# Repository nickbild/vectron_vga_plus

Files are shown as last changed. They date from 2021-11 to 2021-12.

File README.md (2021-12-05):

# Vectron VGA Plus

Vectron VGA Plus generates a 640x480@60Hz VGA signal and has an interface that works with retro computers or microcontrollers.

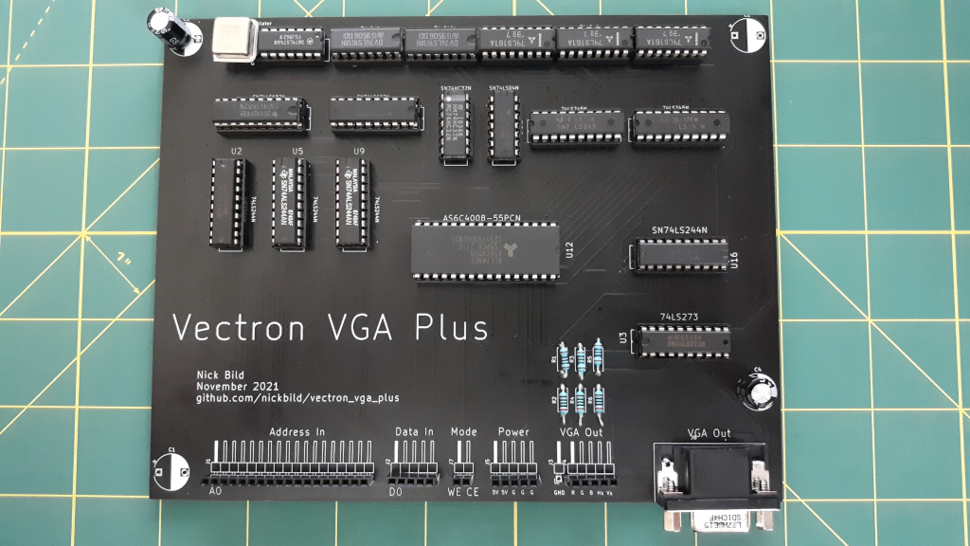
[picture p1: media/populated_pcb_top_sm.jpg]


Screenshot of Vectron VGA Plus running a demo:
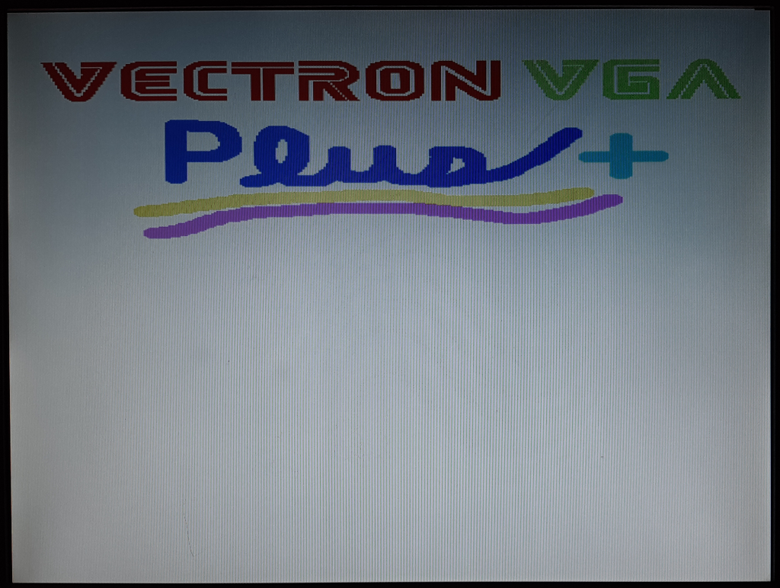
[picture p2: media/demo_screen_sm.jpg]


## How It Works

I previously built a massive 7400-logic based VGA generator called [Vectron VGA](https://github.com/nickbild/vectron_vga).  While it was a nice project to build, it is huge, and not very practical to keep around for use in lots of other projects.  I built Vectron VGA Plus as a much smaller, simpler alternative.

The key change that simplified the design was to use more RAM and less logic.  So, for example, instead of having counters and flip flops, etc. to time each horizontal sync, that logic is embedded in the data in memory.  This new design was also used to create a PCB, and the KiCad files are [here](https://github.com/nickbild/vectron_vga_plus/tree/main/vectron_vga_plus_design).

The general overview of the design goes like this: a 25.175 MHz pixel clock (divided in half by a flip flop) is used to trigger a chain of 4 bit counter chips.  These counters form an address in memory, and bits from the data stored at that memory location represent red, green, blue, horizontal sync, and vertical sync.  When the end of a frame is reached, magnitude comparators reset the counters, and it all starts over for the next frame.

Of course you also need to get data *in* to the RAM, so there are some buffer chips and mode selection signals to allow an external device (e.g. retro computer or microcontroller) to take over bus control and write RAM as needed.

As I mentioned, the 25.175 MHz clock has been divided by 2, which yields a viewable resolution of 320 horizontal pixels.  To keep logic simple, the vertical resolution is kept at 480 lines, technically giving an odd resolution of 320x480, but it is expected that in actual use, the external device is going to double up horizontal lines, giving a standard resolution of 320x240.  3-bit color was implemented, yielding a palette of 8 colors.

Since even non-visible screen regions need to be represented in the RAM (for blanking periods and V-sync/H-sync timings), RAM usage is higher -- 320x480 requires 210KB of video RAM (I used a 512KB chip that I had on hand, but a 256KB chip would be sufficient).  That's a bit extravagant for the 80s-esque 6502-based retro computers that I build, but it's also, I think, within bounds for a pure retro device (as opposed to using a microcontroller or FPGA).  In addition to the reduction in chip count, this design also pays off in flexibility; timings can be tweaked by adjusting the contents of memory, even after the PCB has been finalized.

## Media

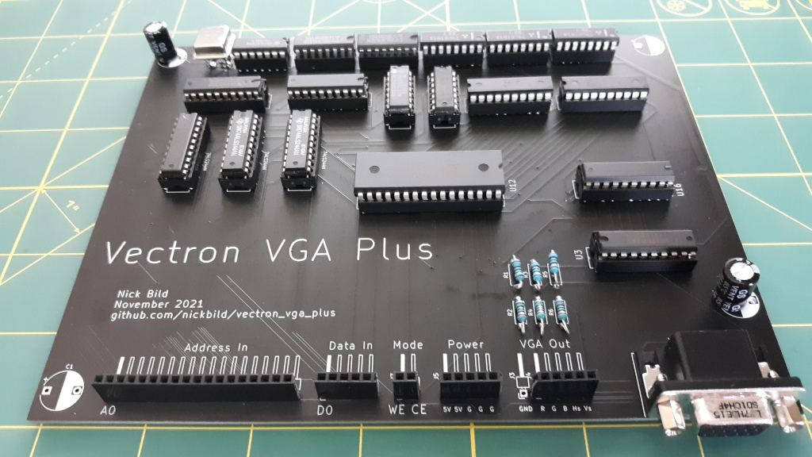
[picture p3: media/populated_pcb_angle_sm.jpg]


An Arduino Mega 2560 sending images to Vectron VGA Plus:

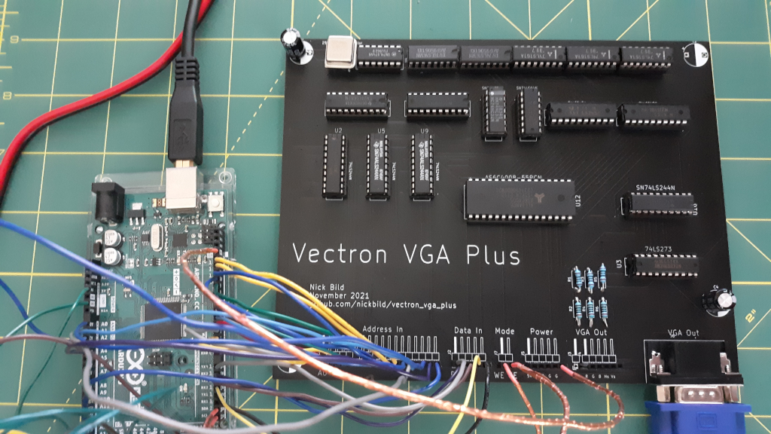
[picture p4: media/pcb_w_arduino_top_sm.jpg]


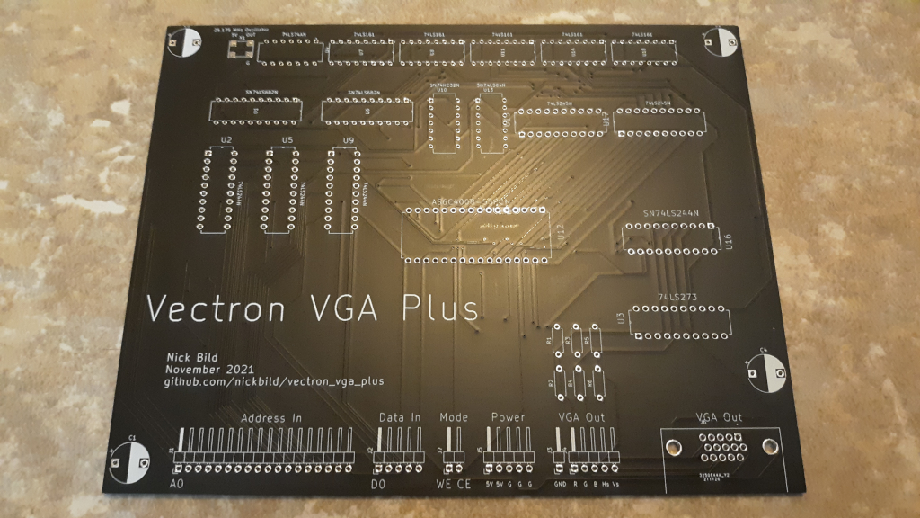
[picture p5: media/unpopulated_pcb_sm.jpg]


Oops!  I picked the wrong footprint for my oscillator!  Fortunately, I could still solder the pins to the pads.

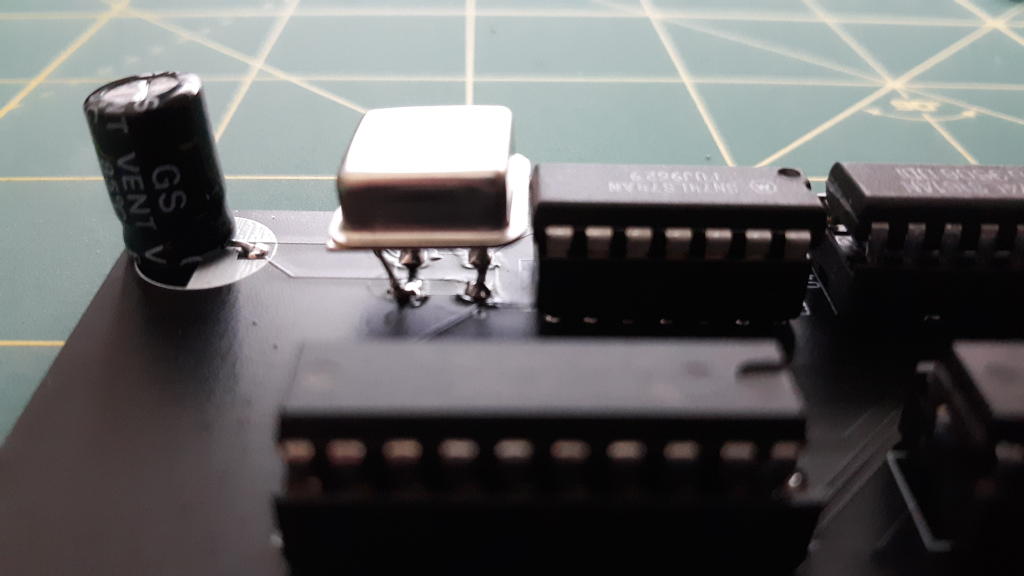
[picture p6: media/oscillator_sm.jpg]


Schematic:



Breadboard prototype of circuit:

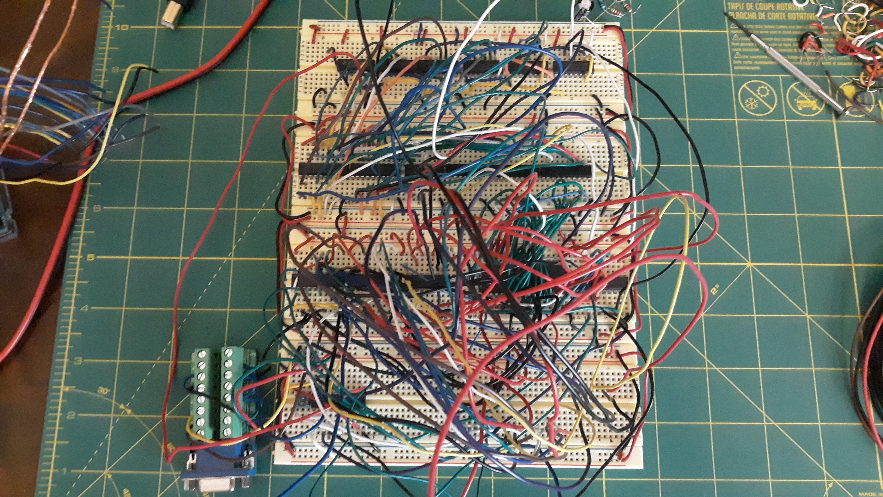
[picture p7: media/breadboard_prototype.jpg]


## Bill of Materials

- 1 x 25.175 MHz oscillator
- 1 x 74LS74AN
- 5 x 74LS161
- 2 x SN74LS682N
- 1 x SN74HC32N
- 1 x 74LS04N
- 2 x SN74LS245N
- 4 x SN74LS244N
- 1 x AS6C4008-55PCN
- 1 x 74LS273
- 3 x 200 ohm resistors
- 3 x 100 ohm resistors
- 2 x 200 uF electrolytic capacitors
- 1 x VGA connector
- 36 x female header pins

## About the Author

[Nick A. Bild, MS](https://nickbild79.firebaseapp.com/#!/)

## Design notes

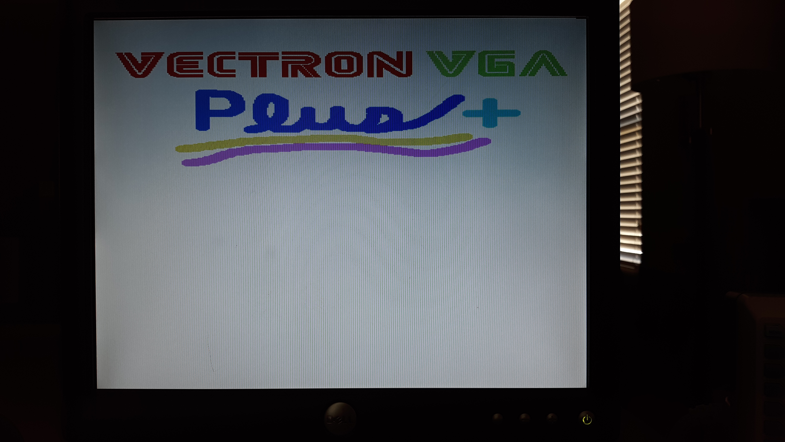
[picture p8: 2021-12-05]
media/demo_screen.jpg

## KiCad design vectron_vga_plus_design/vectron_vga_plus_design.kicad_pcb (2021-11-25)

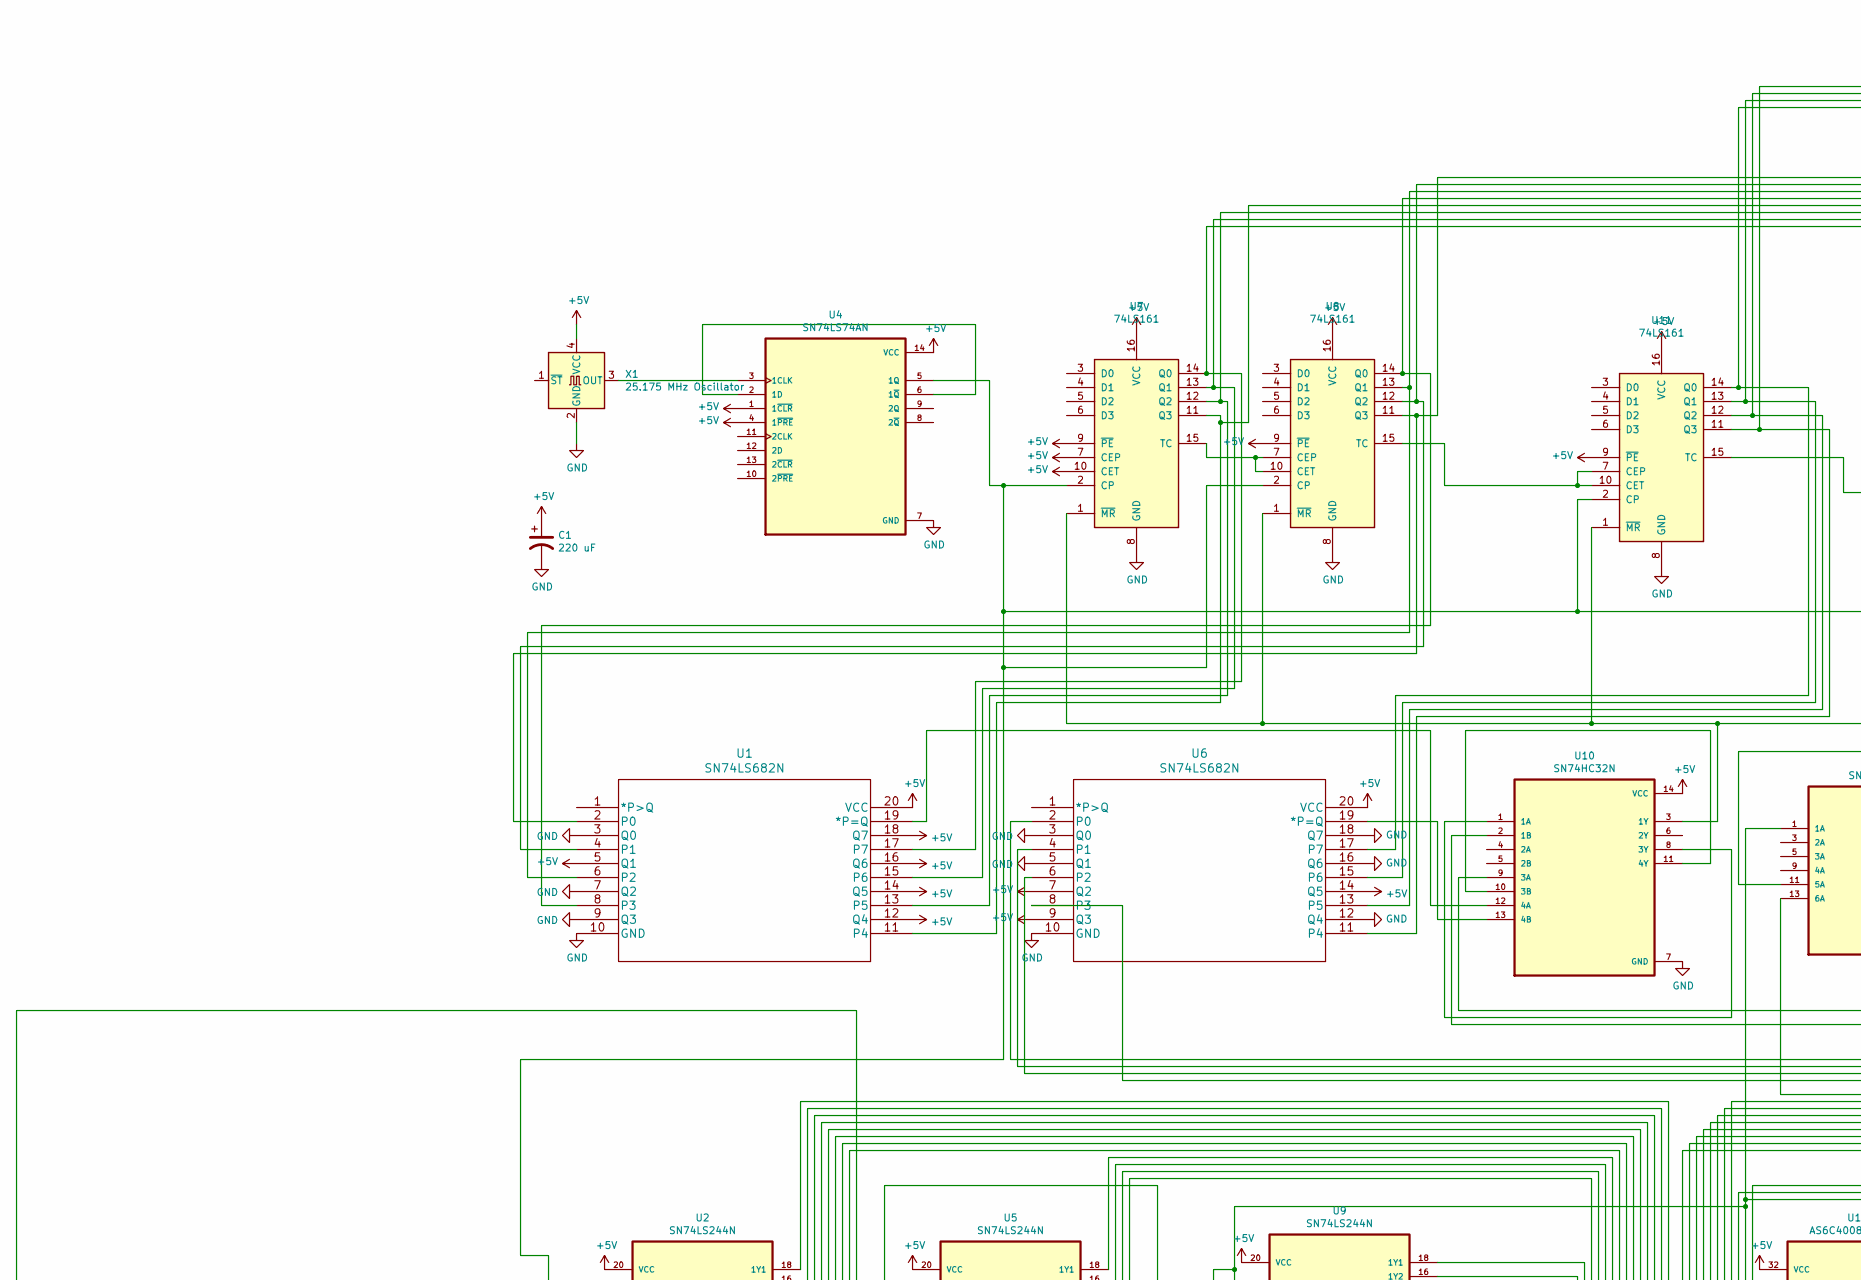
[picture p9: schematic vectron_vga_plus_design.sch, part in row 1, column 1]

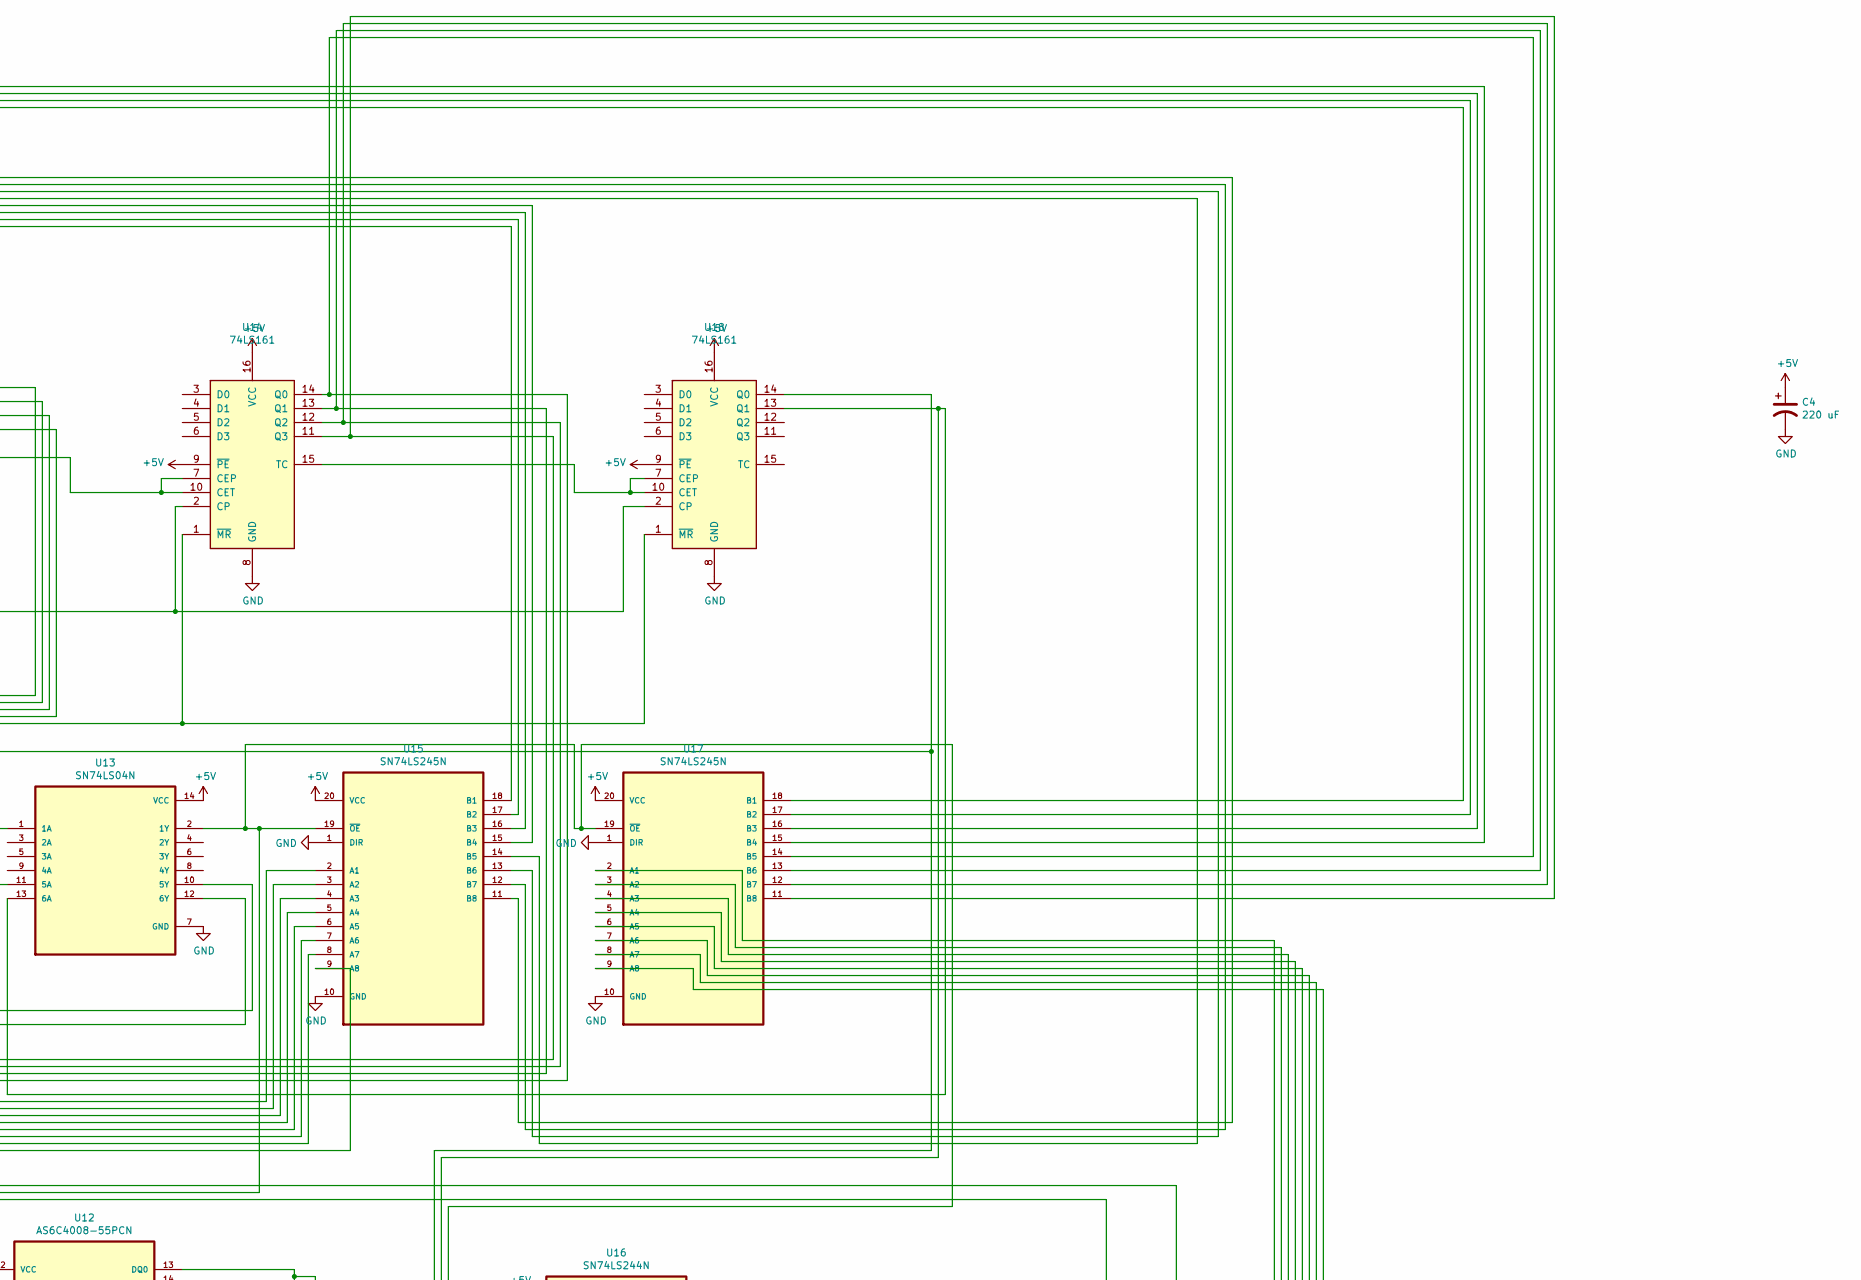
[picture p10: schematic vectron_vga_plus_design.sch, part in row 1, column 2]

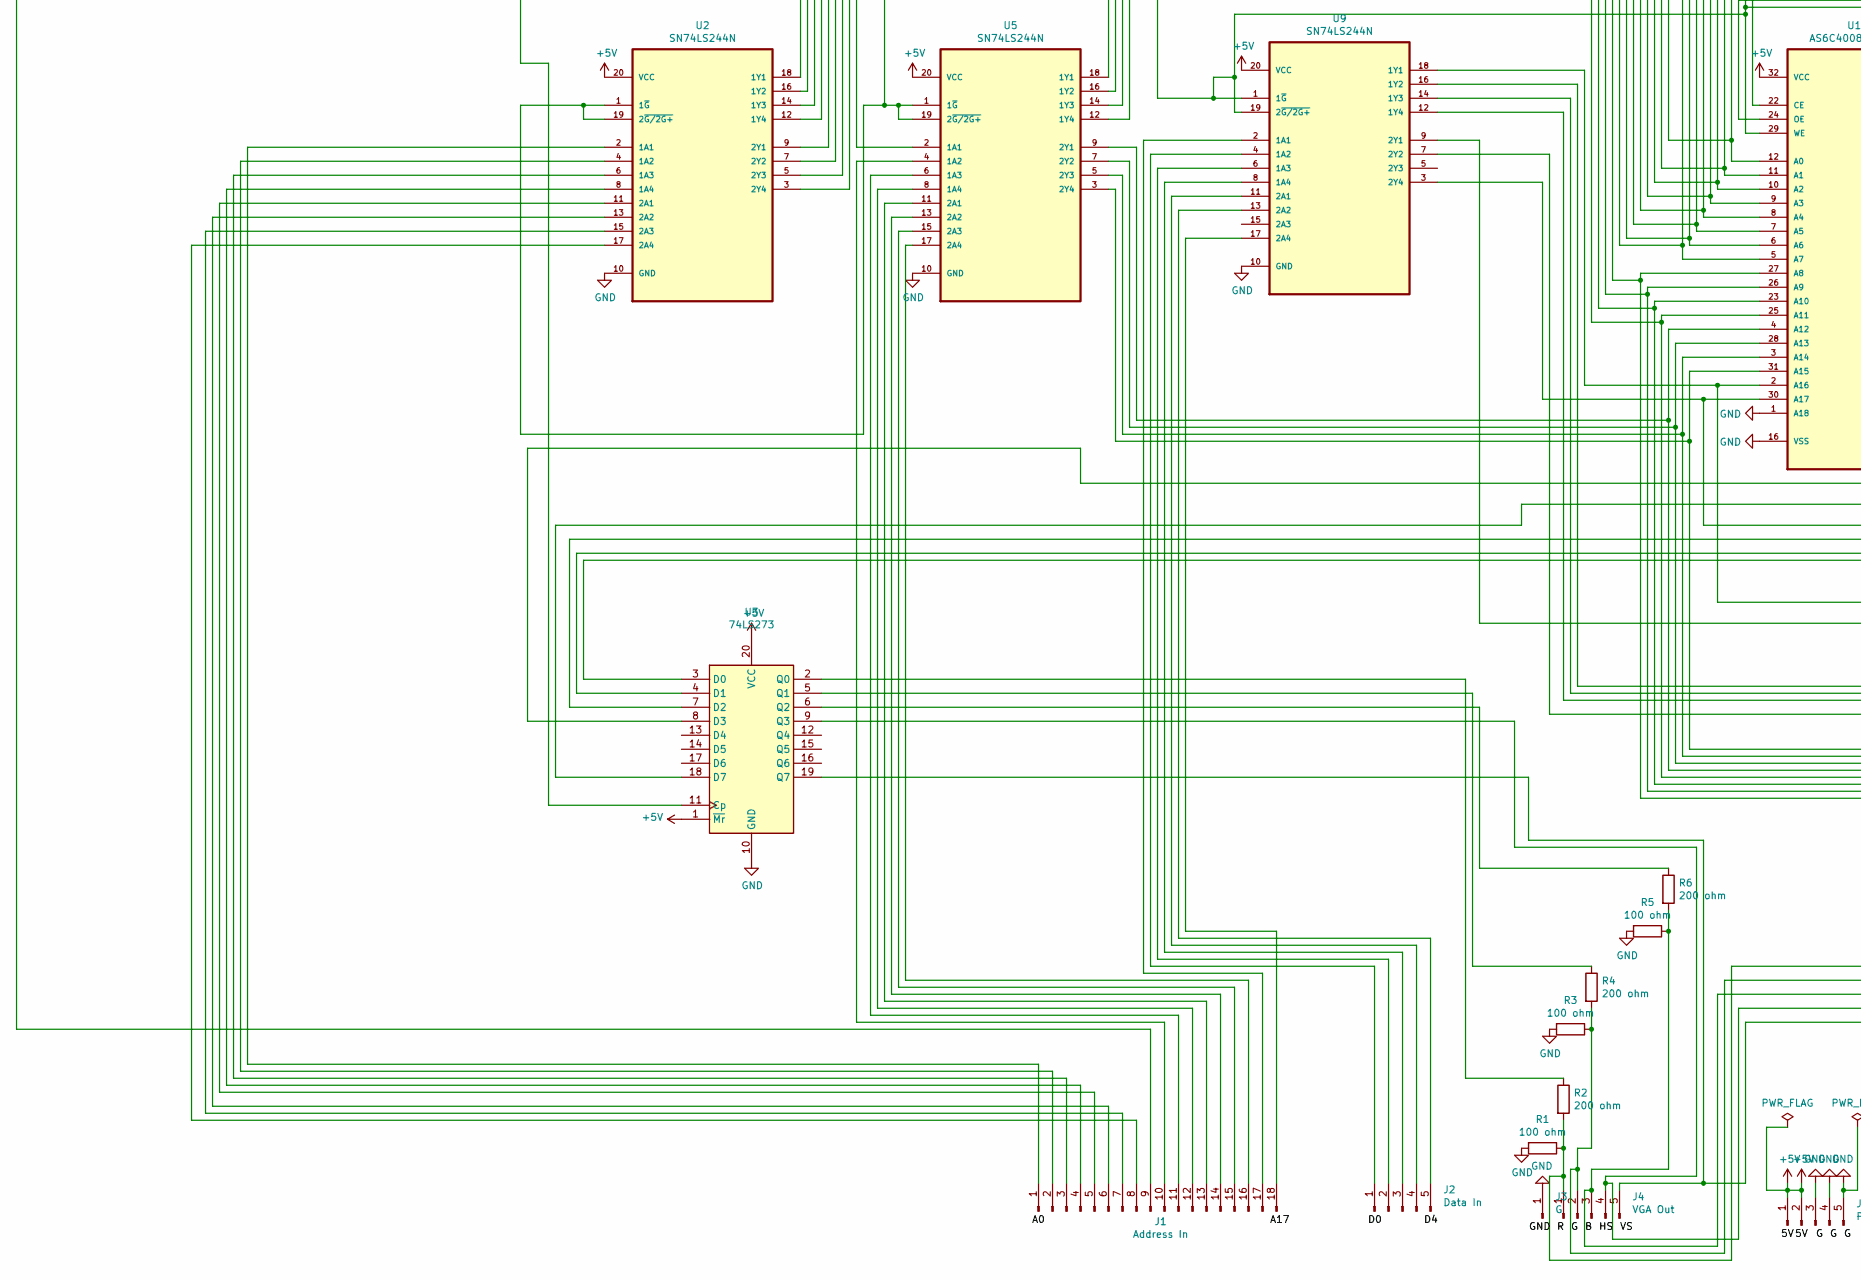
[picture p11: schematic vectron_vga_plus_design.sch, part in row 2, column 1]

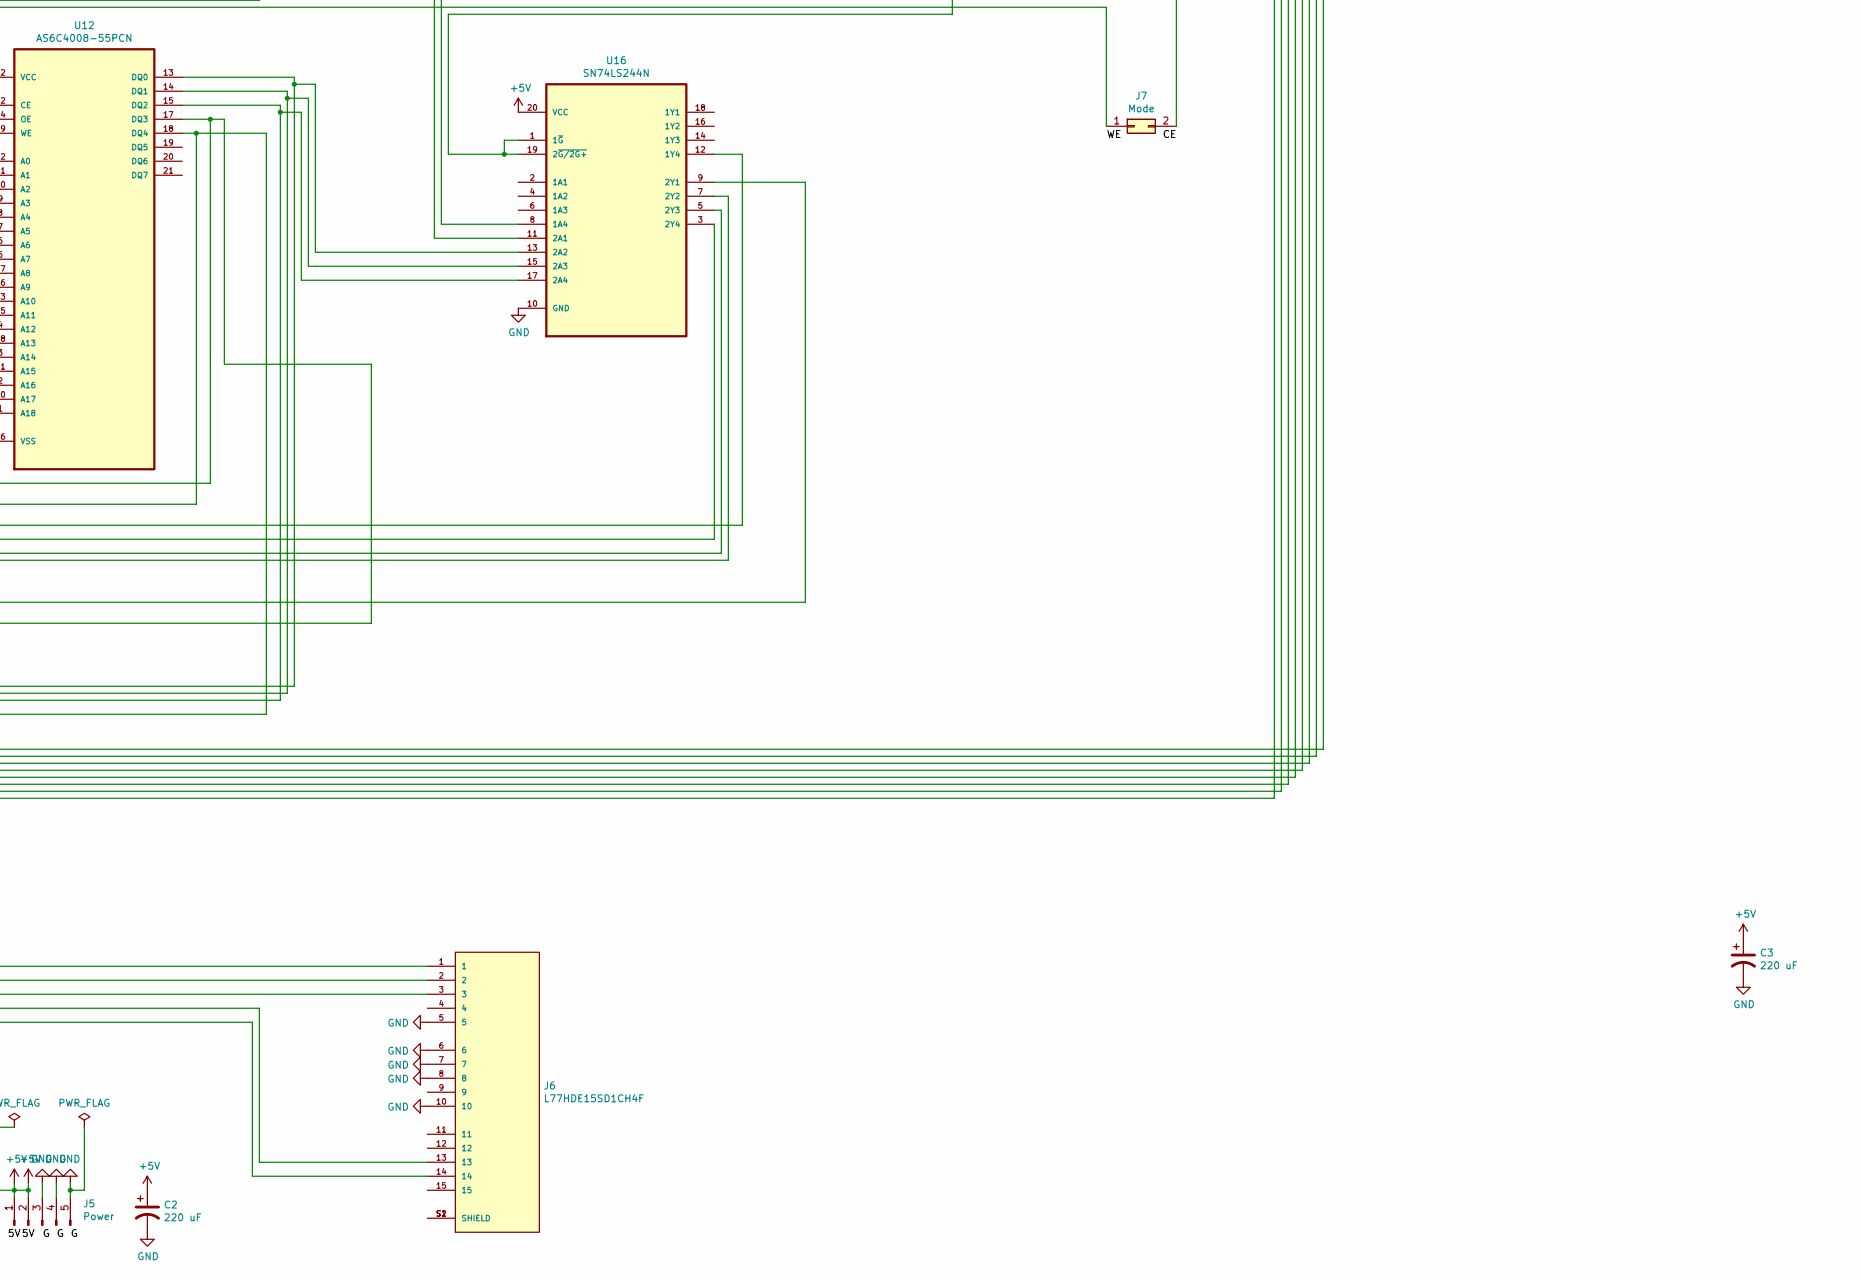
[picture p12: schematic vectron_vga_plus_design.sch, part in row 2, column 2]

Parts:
C1, C2, C3, C4: 220 uF; CP_Radial_D10.0mm_P7.50mm
J1: Address In; PinHeader_1x18_P2.54mm_Horizontal
J2: Data In; PinHeader_1x05_P2.54mm_Horizontal
J3: G; PinHeader_1x01_P2.54mm_Horizontal
J4: VGA Out; PinHeader_1x05_P2.54mm_Horizontal
J5: Power; PinHeader_1x05_P2.54mm_Horizontal
J6: L77HDE15SD1CH4F; AMPHENOL_L77HDE15SD1CH4F; PARTREV N/A
J7: Mode; PinHeader_1x02_P2.54mm_Horizontal
R1, R3, R5: 100 ohm; R_Axial_DIN0207_L6.3mm_D2.5mm_P7.62mm_Horizontal
R2, R4, R6: 200 ohm; R_Axial_DIN0207_L6.3mm_D2.5mm_P7.62mm_Horizontal
U1, U6: SN74LS682N
U2, U5, U9, U16: SN74LS244N; DIP254P762X508-20; MPN SN74LS244N
U3: 74LS273; DIP254P762X508-20
U4: SN74LS74AN; DIP794W45P254L1969H508Q14
U7, U8, U11, U14, U18: 74LS161; SN74LS161AN
U10: SN74HC32N; DIP794W45P254L1969H508Q14
U12: AS6C4008-55PCN; DIP254P1524X393-32; MPN AS6C4008-55PCN
U13: SN74LS04N; DIP794W45P254L1969H508Q14
U15, U17: SN74LS245N; DIP254P762X508-20; MPN SN74LS245N
X1: 25.175 MHz Oscillator; Oscillator_SMD_SeikoEpson_SG8002CA-4Pin_7.0x5.0mm

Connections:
+5V: C1.1, C2.1, C3.1, C4.1, J5.1, J5.2, U1.5 (Q1), U1.12 (Q4), U1.14 (Q5), U1.16 (Q6), U1.18 (Q7), U1.20 (VCC), U2.20 (VCC), U3.1 (~Mr), U3.20 (VCC), U4.1 (1~CLR), U4.4 (1~PRE), U4.14 (VCC), U5.20 (VCC), U6.7 (Q2), U6.9 (Q3), U6.14 (Q5), U6.20 (VCC), U7.7 (CEP), U7.9 (~PE), U7.10 (CET), U7.16 (VCC), U8.9 (~PE), U8.16 (VCC), U9.20 (VCC), U10.14 (VCC), U11.9 (~PE), U11.16 (VCC), U12.32 (VCC), U13.14 (VCC), U14.9 (~PE), U14.16 (VCC), U15.20 (VCC), U16.20 (VCC), U17.20 (VCC), U18.9 (~PE), U18.16 (VCC), X1.4 (VCC)
/B: J4.3, J6.3, R5.1, R6.2
/G: J4.2, J6.2, R3.1, R4.2
GND: C1.2, C2.2, C3.2, C4.2, J3.1, J5.3, J5.4, J5.5, J6.5, J6.6, J6.7, J6.8, J6.10, R1.2, R3.2, R5.2, U1.3 (Q0), U1.7 (Q2), U1.9 (Q3), U1.10 (GND), U2.10 (GND), U3.10 (GND), U4.7 (GND), U5.10 (GND), U6.3 (Q0), U6.5 (Q1), U6.10 (GND), U6.12 (Q4), U6.16 (Q6), U6.18 (Q7), U7.8 (GND), U8.8 (GND), U9.10 (GND), U10.7 (GND), U11.8 (GND), U12.1 (A18), U12.16 (VSS), U13.7 (GND), U14.8 (GND), U15.1 (DIR), U15.10 (GND), U16.10 (GND), U17.1 (DIR), U17.10 (GND), U18.8 (GND), X1.2 (GND)
unnamed: J1.1, U2.2 (1A1)
unnamed: J1.2, U2.4 (1A2)
unnamed: J1.3, U2.6 (1A3)
unnamed: J1.4, U2.8 (1A4)
unnamed: J1.5, U2.11 (2A1)
unnamed: J1.6, U2.13 (2A2)
unnamed: J1.7, U2.15 (2A3)
unnamed: J1.8, U2.17 (2A4)
unnamed: J1.9, U5.2 (1A1)
unnamed: J1.10, U5.4 (1A2)
unnamed: J1.11, U5.6 (1A3)
unnamed: J1.12, U5.8 (1A4)
unnamed: J1.13, U5.11 (2A1)
unnamed: J1.14, U5.13 (2A2)
unnamed: J1.15, U5.15 (2A3)
unnamed: J1.16, U5.17 (2A4)
unnamed: J1.17, U9.2 (1A1)
unnamed: J1.18, U9.17 (2A4)
unnamed: J2.1, U9.4 (1A2)
unnamed: J2.2, U9.6 (1A3)
unnamed: J2.3, U9.8 (1A4)
unnamed: J2.4, U9.11 (2A1)
unnamed: J2.5, U9.13 (2A2)
unnamed: J4.1, J6.1, R1.1, R2.2
unnamed: J4.4, J6.13, U3.9 (Q3)
unnamed: J4.5, J6.14, U3.19 (Q7)
unnamed: J6.S1 (SHIELD), J6.S2 (SHIELD)
unnamed: J7.1, U2.1 (1~G), U2.19 (2~G/2G+), U5.1 (1~G), U5.19 (2~G/2G+), U9.1 (1~G), U9.19 (2~G/2G+), U12.29 (WE), U13.1 (1A)
unnamed: J7.2, U12.22 (CE)
unnamed: R2.1, U3.2 (Q0)
unnamed: R4.1, U3.5 (Q1)
unnamed: R6.1, U3.6 (Q2)
unnamed: U1.2 (P0), U8.11 (Q3), U15.11 (B8)
unnamed: U1.4 (P1), U8.12 (Q2), U15.12 (B7)
unnamed: U1.6 (P2), U8.13 (Q1), U15.13 (B6)
unnamed: U1.8 (P3), U8.14 (Q0), U15.14 (B5)
unnamed: U1.11 (P4), U7.11 (Q3), U15.15 (B4)
unnamed: U1.13 (P5), U7.12 (Q2), U15.16 (B3)
unnamed: U1.15 (P6), U7.13 (Q1), U15.17 (B2)
unnamed: U1.17 (P7), U7.14 (Q0), U15.18 (B1)
unnamed: U1.19 (*P=Q), U10.12 (4A)
unnamed: U4.2 (1D), U4.6 (1~Q)
unnamed: U4.3 (1CLK), X1.3 (OUT)
unnamed: U7.15 (TC), U8.7 (CEP), U8.10 (CET)
unnamed: U10.1 (1A), U10.8 (3Y)
unnamed: U10.2 (1B), U13.12 (6Y)
unnamed: U7.1 (~MR), U8.1 (~MR), U10.3 (1Y), U11.1 (~MR), U14.1 (~MR), U18.1 (~MR)
unnamed: U10.9 (3A), U13.10 (5Y)
unnamed: U10.10 (3B), U10.11 (4Y)
unnamed: U6.19 (*P=Q), U10.13 (4B)
unnamed: U3.11 (Cp), U4.5 (1Q), U7.2 (CP), U8.2 (CP), U11.2 (CP), U14.2 (CP), U18.2 (CP)
unnamed: U8.15 (TC), U11.7 (CEP), U11.10 (CET)
unnamed: U6.11 (P4), U11.11 (Q3), U17.15 (B4)
unnamed: U6.13 (P5), U11.12 (Q2), U17.16 (B3)
unnamed: U6.15 (P6), U11.13 (Q1), U17.17 (B2)
unnamed: U6.17 (P7), U11.14 (Q0), U17.18 (B1)
unnamed: U11.15 (TC), U14.7 (CEP), U14.10 (CET)
unnamed: U9.18 (1Y1), U12.2 (A16), U16.9 (2Y1)
unnamed: U5.5 (2Y3), U12.3 (A14), U17.8 (A7)
unnamed: U5.9 (2Y1), U12.4 (A12), U17.6 (A5)
unnamed: U2.3 (2Y4), U12.5 (A7), U15.9 (A8)
unnamed: U2.5 (2Y3), U12.6 (A6), U15.8 (A7)
unnamed: U2.7 (2Y2), U12.7 (A5), U15.7 (A6)
unnamed: U2.9 (2Y1), U12.8 (A4), U15.6 (A5)
unnamed: U2.12 (1Y4), U12.9 (A3), U15.5 (A4)
unnamed: U2.14 (1Y3), U12.10 (A2), U15.4 (A3)
unnamed: U2.16 (1Y2), U12.11 (A1), U15.3 (A2)
unnamed: U2.18 (1Y1), U12.12 (A0), U15.2 (A1)
unnamed: U9.16 (1Y2), U12.13 (DQ0), U16.13 (2A2)
unnamed: U9.14 (1Y3), U12.14 (DQ1), U16.15 (2A3)
unnamed: U9.12 (1Y4), U12.15 (DQ2), U16.17 (2A4)
unnamed: U3.8 (D3), U9.9 (2Y1), U12.17 (DQ3)
unnamed: U3.18 (D7), U9.7 (2Y2), U12.18 (DQ4)
unnamed: U5.14 (1Y3), U12.23 (A10), U17.4 (A3)
unnamed: U12.24 (OE), U13.2 (1Y), U15.19 (~OE), U16.1 (1~G), U16.19 (2~G/2G+), U17.19 (~OE)
unnamed: U5.12 (1Y4), U12.25 (A11), U17.5 (A4)
unnamed: U5.16 (1Y2), U12.26 (A9), U17.3 (A2)
unnamed: U5.18 (1Y1), U12.27 (A8), U17.2 (A1)
unnamed: U5.7 (2Y2), U12.28 (A13), U17.7 (A6)
unnamed: U9.3 (2Y4), U12.30 (A17), U16.12 (1Y4)
unnamed: U5.3 (2Y4), U12.31 (A15), U17.9 (A8)
unnamed: U13.11 (5A), U16.11 (2A1), U18.14 (Q0)
unnamed: U13.13 (6A), U16.8 (1A4), U18.13 (Q1)
unnamed: U6.2 (P0), U14.11 (Q3), U17.11 (B8)
unnamed: U6.4 (P1), U14.12 (Q2), U17.12 (B7)
unnamed: U6.6 (P2), U14.13 (Q1), U17.13 (B6)
unnamed: U6.8 (P3), U14.14 (Q0), U17.14 (B5)
unnamed: U14.15 (TC), U18.7 (CEP), U18.10 (CET)
unnamed: U3.7 (D2), U16.3 (2Y4)
unnamed: U3.4 (D1), U16.5 (2Y3)
unnamed: U3.3 (D0), U16.7 (2Y2)

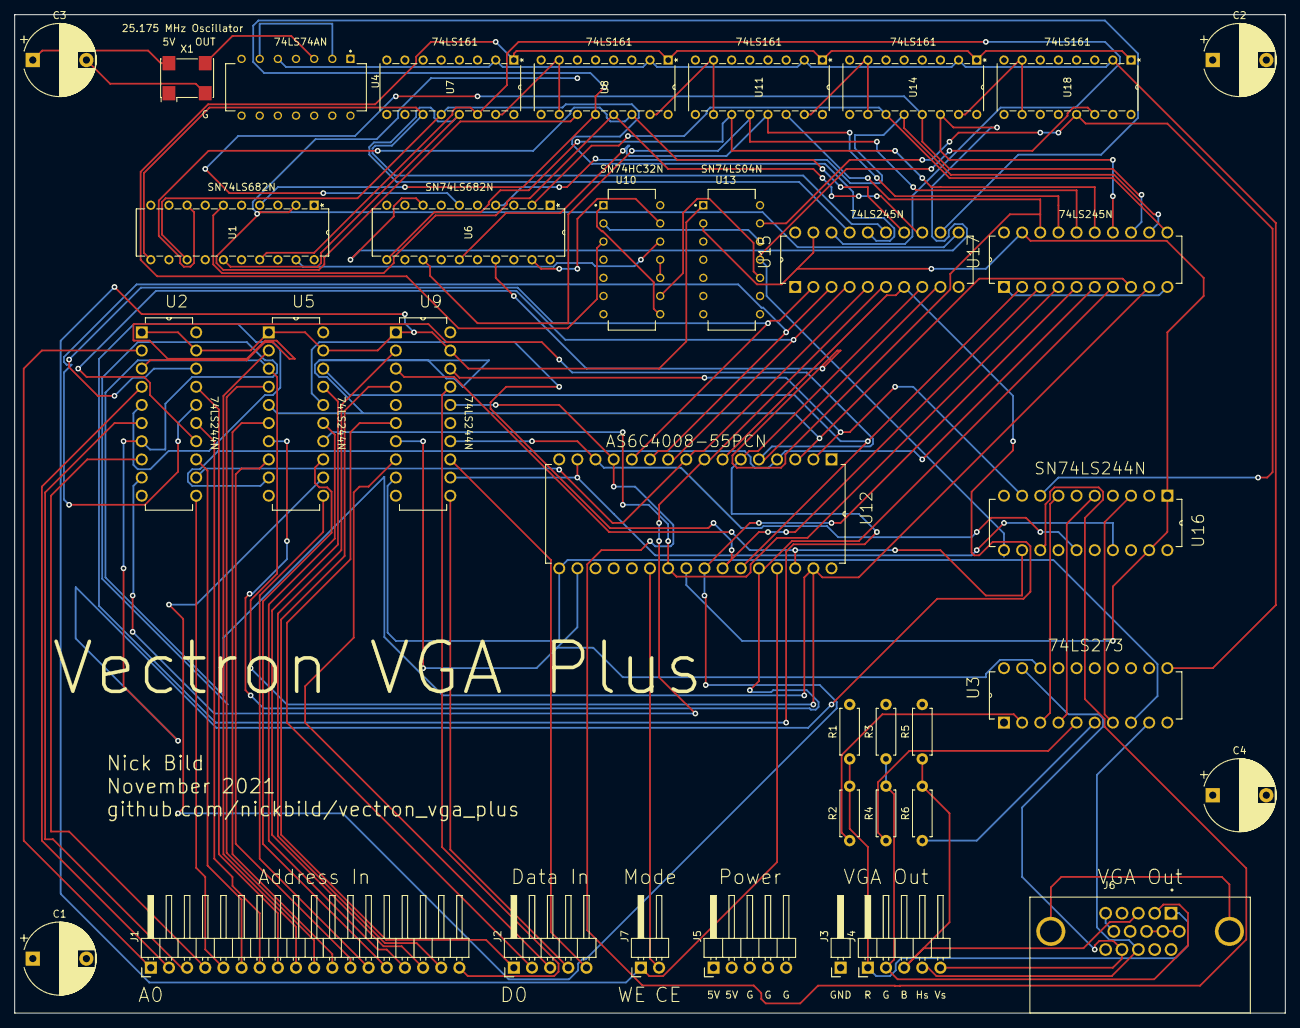
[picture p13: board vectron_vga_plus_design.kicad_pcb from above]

Board: 4 copper layers, 177.8 x 139.7 mm, 36 parts (0 on the bottom side), 95 nets.

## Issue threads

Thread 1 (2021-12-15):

Add license information

vazhnov, 2021-12-15:
Hello!

I found this repository from https://hackaday.com/2021/12/14/a-slim-7400-logic-vga-board-for-all-your-retro-needs/

Could you please add information about the license of this repository — is it allowed to copy, change and use the code and images in any purpose?
It would be great to see any popular open source license.

nickbild, 2021-12-16:
Done.

vazhnov, 2021-12-16:
MIT — amazing!
@nickbild, thank you very much!

Closed 2021-12-16.

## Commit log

2021-11-19 Add Arduino Mega code for testing.
2021-11-21 Save progress on design files.
    [vectron_vga_plus_design.kicad_pcb, vectron_vga_plus_design.sch]
2021-12-05 Fix Arduino tester and add gerber files.
    [vectron_vga_plus_design-B_Cu.gbl, vectron_vga_plus_design-B_Mask.gbs, vectron_vga_plus_design-B_Paste.gbp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]

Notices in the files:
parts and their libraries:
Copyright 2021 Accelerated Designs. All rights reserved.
